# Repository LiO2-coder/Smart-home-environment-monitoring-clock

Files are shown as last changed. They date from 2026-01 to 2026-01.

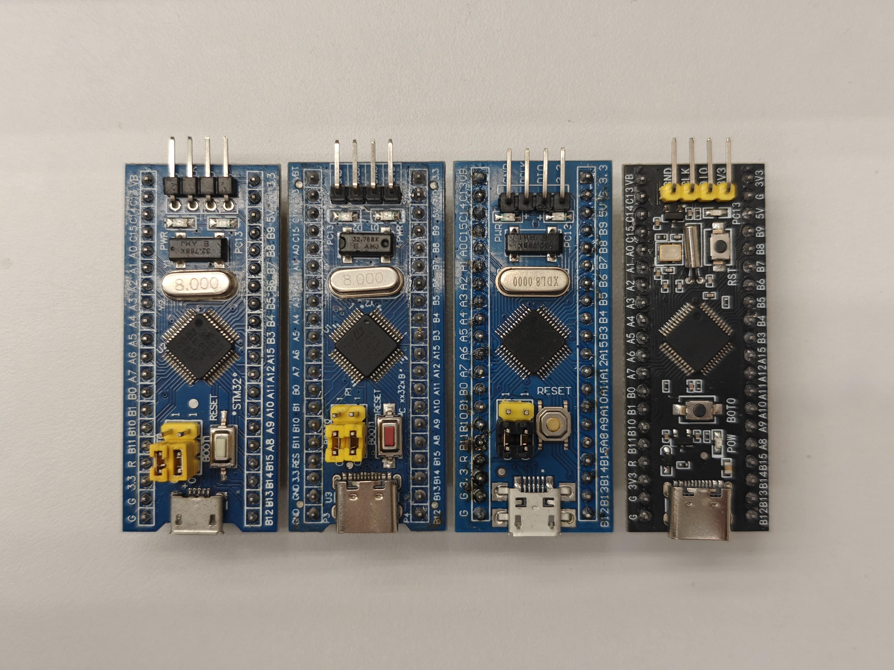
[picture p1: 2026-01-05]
images/调试时-统一使用c8t6.jpg

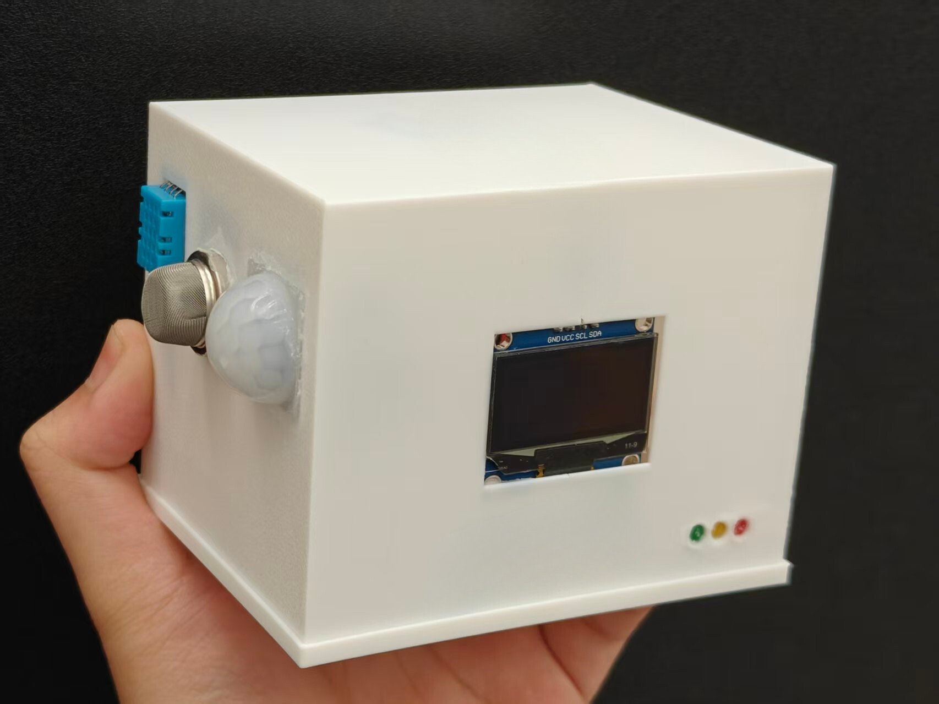
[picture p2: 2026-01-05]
产品实物.jpg

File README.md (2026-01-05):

# 智能居家环境监测时钟系统

## 项目概述
本项目是一个基于STM32与ESP32双核架构的智能家居环境监测时钟系统，实现了环境感知（温湿度、烟雾浓度、光照）、实时时钟显示、语音交互及云端协同等完整功能链。系统创新性地采用人体存在检测雷达触发分级功耗管理，在无人状态下自动进入低功耗模式，整体功耗降低30%以上。

## 核心功能
- **环境监测**：实时采集温湿度、烟雾浓度、光照强度等环境参数
- **智能预警**：多级烟雾浓度预警系统，响应延迟<2秒
- **低功耗管理**：人体存在检测自动触发省电模式
- **双核协同**：STM32负责本地控制，ESP32处理网络通信
- **语音交互**：支持基础语音指令识别与反馈

## 系统架构

### 硬件架构
系统采用模块化设计，STM32作为主控制器，ESP32作为通信协处理器：

### 软件流程
系统启动后并行执行本地控制与网络通信任务：

## 硬件设计

### 硬件连接
项目采用STM32F103ZET6作为主控芯片，外接多种传感器模块：

### 引脚配置
| 序号 | 引脚号 | 连接元件引脚 | 连接元件 |
|---|---|---|---|
| 1 | PA1 | AO | MQ2烟雾传感器 |
| 2 | PA9 | RX | ESP32 AI系统 |
| 3 | PA10 | TX | ESP32 AI系统 |
| 4 | PB0 | OUT | HW416人体检测模块 |
| 5 | PB6 | SCL | OLED显示模块 |
| 6 | PB7 | SDA | OLED显示模块 |

### 实物连接
调试阶段采用杜邦线连接各模块：

## 软件设计

### MQ2烟雾传感器模块
采用ADC采集实现烟雾浓度实时监测：

```c
// ADC初始化配置
hadc1.Instance = ADC1;
hadc1.Init.ScanConvMode = ADC_SCAN_DISABLE;
hadc1.Init.ContinuousConvMode = ENABLE;
```

### 烟雾浓度预警系统
多级阈值触发与分级恢复机制：

```c
typedef enum {
    ALARM_LEVEL_INFO = 0,    // 正常状态
    ALARM_LEVEL_WARNING,     // 警告状态
    ALARM_LEVEL_ERROR,       // 错误状态
} Alarm_Level_t;
```

### DHT11温湿度传感器
单总线通信协议实现数据采集：

```c
void DHT11_IO_OUT() {
    GPIO_InitStruct.Mode = GPIO_MODE_OUTPUT_PP;
    HAL_GPIO_Init(GPIOG, &GPIO_InitStruct);
}
```

### OLED显示模块
开源SSD1306驱动移植，实现信息可视化：

正常显示界面：

省电模式界面：

### RTC实时时钟
后备寄存器机制确保时间持续运行：

```c
void YY_RTC_Init(void) {
    uint32_t initFlag = HAL_RTCEx_BKUPRead(&hrtc, RTC_BKP_DR1);
    if (initFlag == RTC_INIT_FLAG_VALUE) return;
    // 初始化代码
}
```

### STM32-ESP32通信协议
自定义串口通信协议实现双核协同：

```
[AA 55][CMD][LEN][DATA...][CRC16][0D]
```

通信时序流程：

## 调试与开发

### 开发环境
- **主控芯片**：STM32F103ZET6（最终版本）
- **调试芯片**：STM32F103C8T6（开发阶段）
- **开发工具**：Keil MDK-ARM、VSCode
- **调试接口**：SWD、串口调试

### 外壳设计
基于产品需求设计3D打印外壳：

## 项目结构

```
SmartEnvClock/
├── Docs/                    # 项目文档
├── Firmware/               # 嵌入式固件
│   │   ├── Core/           # 核心驱动
│   │   ├── Drivers/        # 硬件驱动
│   │   └── Projects/       # 项目文件
│   └── ESP32/              # ESP32端代码
├── Hardware/               # 硬件设计文件
│   └── 3D_Models/         # 3D外壳模型
└── README.md               # 项目说明
```

## 快速开始

### 硬件准备
1. STM32F103ZET6开发板
2. ESP32-WROOM-32模块
3. OLED显示屏（SSD1306）
4. MQ-2烟雾传感器
5. DHT11温湿度传感器
6. HW416人体检测模块

### 软件编译
1. 克隆仓库
```bash
git clone https://github.com/LiO2-coder/Smart-home-environment-monitoring-clock.git
```

2. 使用Keil打开项目
```bash
打开 /Projects/SAC.uvprojx
```

3. 配置ESP32开发环境
```bash
cd Firmware/ESP32
idf.py build
```

## 通信协议详解

### 协议帧格式
```
帧头(2B) + 命令码(1B) + 数据长度(1B) + 数据(NB) + CRC16(2B) + 帧尾(1B)
```

### 命令码定义
| 命令码 | 功能说明 | 数据长度 |
|---|---|---|
| 0x01 | 请求环境数据 | 0 |
| 0x02 | 请求特定传感器 | 1 |
| 0x10 | 响应就绪 | 0 |
| 0x11 | 发送环境数据 | 20 |

## 性能指标

- **温度测量精度**：±1℃
- **湿度测量精度**：±1%RH
- **烟雾报警响应时间**：<2秒
- **时钟日误差**：<3秒
- **功耗（正常模式）**：120mA
- **功耗（省电模式）**：65mA

## 贡献指南

欢迎提交Issue和Pull Request！主要开发方向包括：

1. **低功耗优化**：进一步降低系统功耗
2. **功能扩展**：增加更多传感器支持
3. **协议优化**：改进通信协议效率
4. **AI集成**：增强本地智能处理能力

## 许可证

本项目采用MIT开源许可证，详见LICENSE文件。

## 联系我们

- 项目主页：https://github.com/LiO2-coder/Smart-home-environment-monitoring-clock
- 问题反馈：https://github.com/LiO2-coder/Smart-home-environment-monitoring-clock/issues
- 邮箱：2099602919@qq.com.com

## 致谢

感谢深圳技术大学嵌入式系统设计课程的支持，特别感谢老师的指导。

---

*最后更新：2026年1月5日*  
*版本号：v1.0.0*

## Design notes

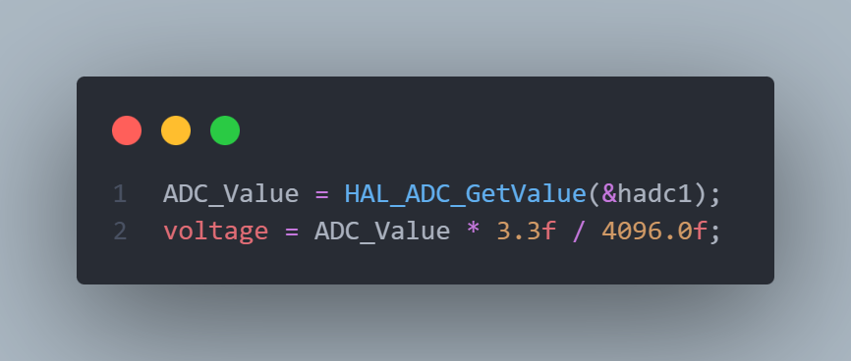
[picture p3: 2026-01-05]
images/MQ2/2.1-ADC-3.png

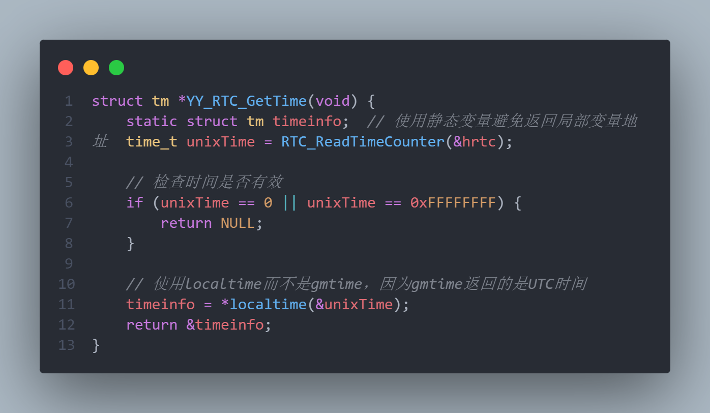
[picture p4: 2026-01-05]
images/rtc/2.5-rtc-4.png

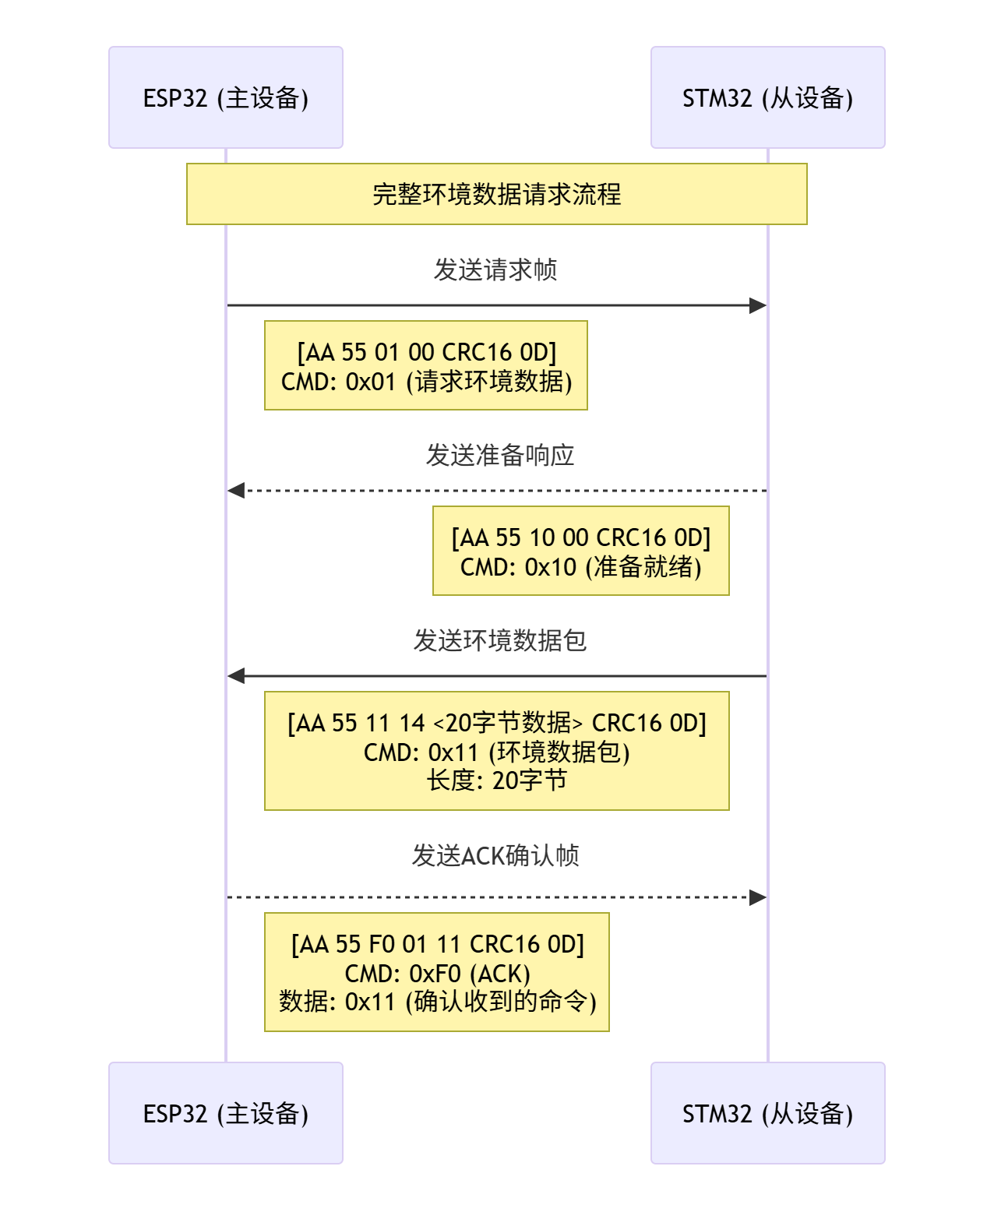
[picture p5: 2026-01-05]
images/双击通信时序流程图.png

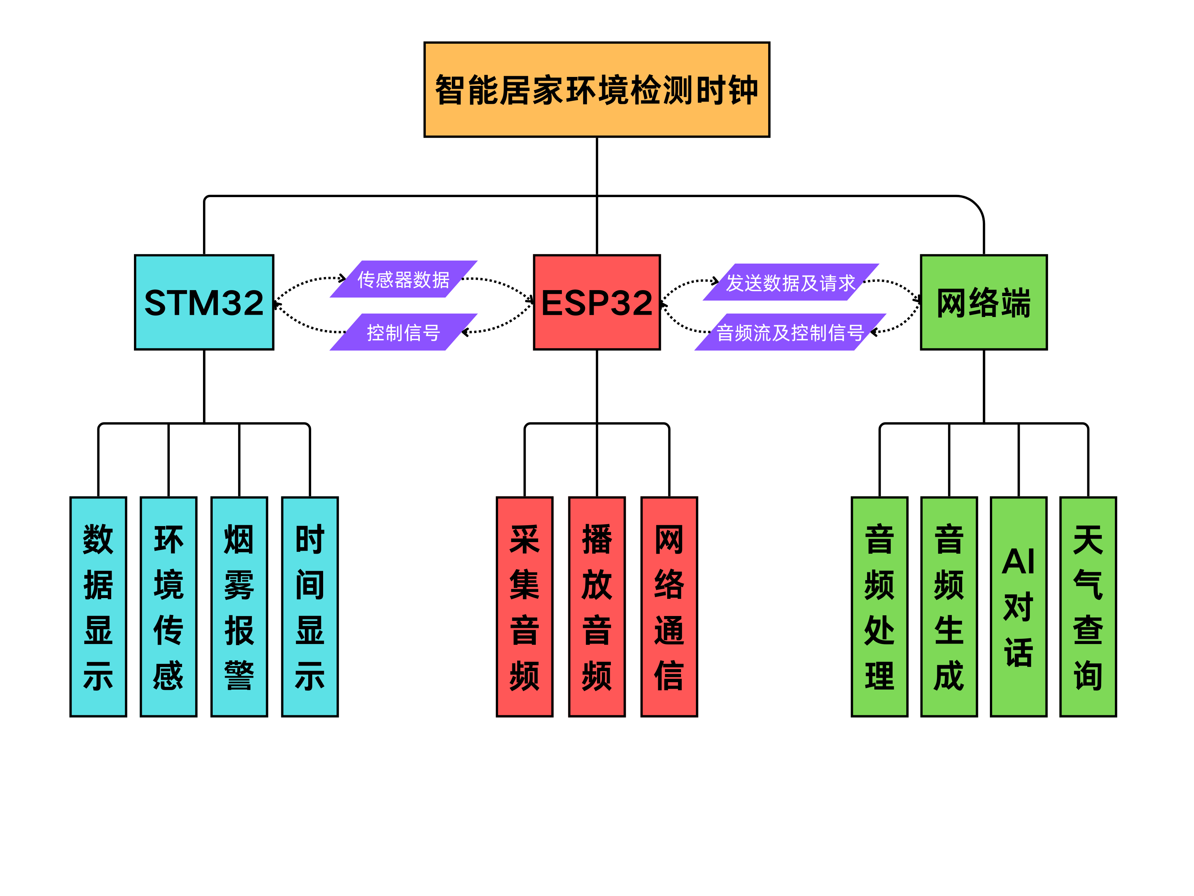
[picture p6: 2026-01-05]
images/框架图.png

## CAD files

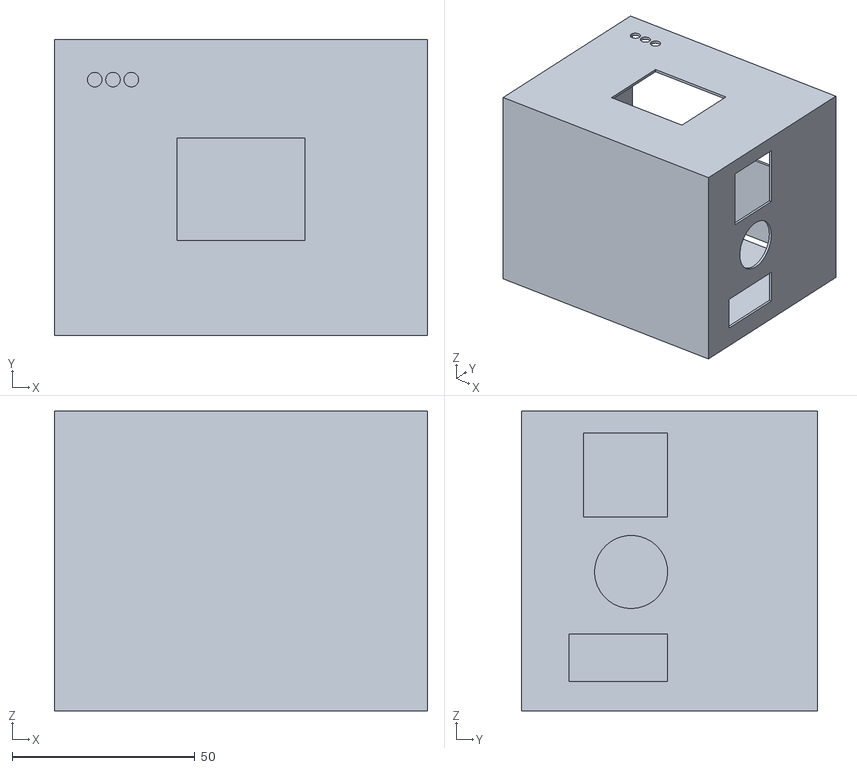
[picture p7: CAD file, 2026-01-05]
Hardware/3D_Models/整体.STL
102.0 x 81.0 x 82.0

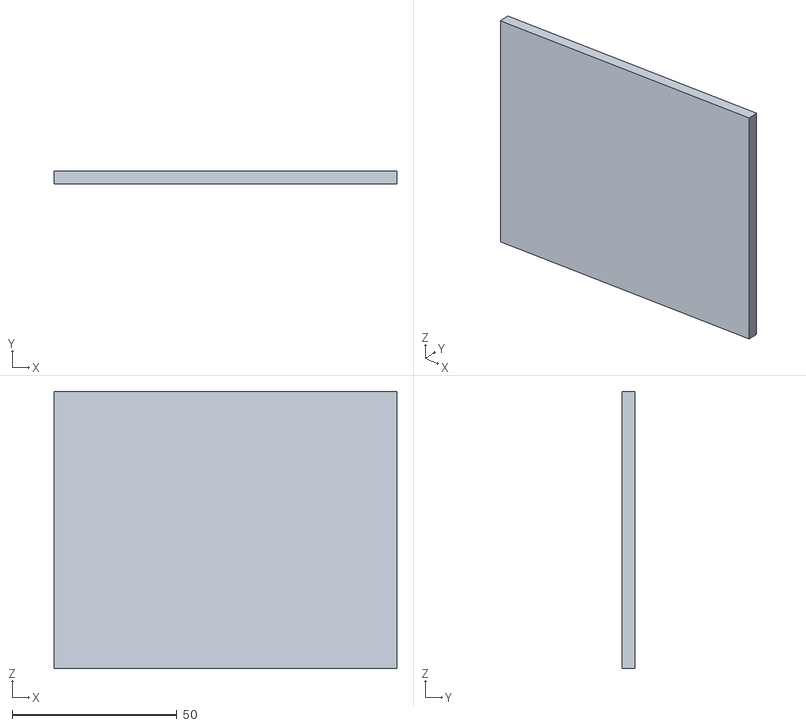
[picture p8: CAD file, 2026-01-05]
Hardware/3D_Models/上盖.STL
104.0 x 4.00 x 84.0

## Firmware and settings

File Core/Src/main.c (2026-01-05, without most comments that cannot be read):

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
/* Includes ------------------------------------------------------------------*/
#include "main.h"
#include "adc.h"
#include "i2c.h"
#include "rtc.h"
#include "gpio.h"

/* USER CODE BEGIN Includes */
#include "oled.h"
#include "DHT11.h"
#include "stdio.h"
#include "string.h"
#include "yy_rtc.h"
#include "Alarm.h"
/* USER CODE END Includes */


void SystemClock_Config(void);
/**
 * @brief  The application entry point.
 * @retval int
 */
int main(void)
{

  /* MCU Configuration--------------------------------------------------------*/

  /* Reset of all peripherals, Initializes the Flash interface and the Systick. */
  HAL_Init();

  /* Configure the system clock */
  SystemClock_Config();

  /* Initialize all configured peripherals */
  MX_GPIO_Init();
  MX_I2C1_Init();
  MX_I2C2_Init();
  MX_ADC1_Init();
  MX_RTC_Init();
  /* USER CODE BEGIN 2 */
  OLED_Init();
  OLED_CLS();


  Alarm_Init();

  // 原有变量定义
  u16 temp = 0;
  u16 humi = 0;
  uint32_t ADC_Value = 0;
  float voltage = 0;
  struct tm *now = NULL;

  char u_temp[20];
  char u_humi[20];
  char u_value[20];
  char ymd[50] = "";
  char hms[50] = "";
  char alarm_status_str[20] = "Status:Normal";

  int fputc(int ch, FILE *f);

  // 显示初始化界面
  OLED_ShowStr(0, 0, "Sensor Monitor", 2);
  OLED_ShowStr(0, 2, "Initializing...", 1);
  HAL_Delay(1000);
  OLED_CLS();
  /* USER CODE END 2 */

  /* Infinite loop */
  /* USER CODE BEGIN WHILE */
  while (1)
  {
    /* USER CODE END WHILE */

    /* USER CODE BEGIN 3 */
    // 如果检测到人体存在
    if (HAL_GPIO_ReadPin(HW416_GPIO_Port, HW416_Pin) == GPIO_PIN_RESET)
    {
      // 正常显示数据


      DHT11_Read_Data(&temp, &humi);


      HAL_GPIO_WritePin(GPIOC, GPIO_PIN_13, GPIO_PIN_RESET);
      HAL_ADC_Start(&hadc1);
      HAL_ADC_PollForConversion(&hadc1, 50);
      ADC_Value = HAL_ADC_GetValue(&hadc1);
      HAL_ADC_Stop(&hadc1);
      HAL_GPIO_WritePin(GPIOC, GPIO_PIN_13, GPIO_PIN_SET);
      voltage = ADC_Value * 3.3f / 4096.0f;

      // 使用新的多级警报系统
      Alarm_Check(voltage);

      // 获取当前警报级别用于显示
      Alarm_Level_t current_level = Alarm_GetCurrentLevel();


      switch (current_level)
      {
      case ALARM_LEVEL_INFO:
        strcpy(alarm_status_str, "Status:Normal");
        break;
      case ALARM_LEVEL_WARNING:
        strcpy(alarm_status_str, "Status:Warning!");
        break;
      case ALARM_LEVEL_ERROR:
        strcpy(alarm_status_str, "Status:ERROR!!");
        break;
      default:
        strcpy(alarm_status_str, "Status:Unknown");
        break;
      }

      // 获取RTC时间
      now = YY_RTC_GetTime();


      sprintf(u_temp, "T:%.1fC", temp / 100.0f);
      sprintf(u_humi, "H:%.1f%%", humi / 100.0f);
      sprintf(u_value, "V:%.2fV", voltage);

      if (now != NULL)
      {
        sprintf(ymd, "%04d-%02d-%02d", now->tm_year + 1900, now->tm_mon + 1, now->tm_mday);
        sprintf(hms, "%02d:%02d:%02d", now->tm_hour, now->tm_min, now->tm_sec);
      }
      else
      {
        strcpy(ymd, "Date: --");
        strcpy(hms, "Time: --");
      }

      // 优化显示布局
      // OLED_CLS();
      OLED_ShowStr(0, 0, (unsigned char *)"Sensor Monitor", 1);
      OLED_ShowStr(100, 0, (unsigned char *)"ON", 1);
      OLED_ShowStr(0, 1, (unsigned char *)u_temp, 1);
      OLED_ShowStr(64, 1, (unsigned char *)u_humi, 1);
      OLED_ShowStr(0, 2, (unsigned char *)u_value, 1);
      OLED_ShowStr(25, 3, (unsigned char *)ymd, 2);
      OLED_ShowStr(32, 5, (unsigned char *)hms, 2);
      OLED_ShowStr(0, 7, (unsigned char *)alarm_status_str, 1);


      /*// char level_indicator[10];
      // sprintf(level_indicator, "Lvl:%d", current_level);
      // OLED_ShowStr(100, 5, (unsigned char *)level_indicator, 1);*/
    }
    else
    {
      // 省电模式显示屏保
      static uint32_t last_blink = 0;
      static uint8_t show_msg = 1;
      uint32_t current_time = HAL_GetTick();

      if (current_time - last_blink > 500)
      {
        show_msg = !show_msg;
        last_blink = current_time;

        OLED_CLS();
        if (show_msg)
        {
          OLED_ShowStr(25, 2.5, (unsigned char *)"Keep Happy", 2);
        }
      }

      // 传感器关闭时重置警报系统
      Alarm_Init();
    }

    HAL_Delay(1000);
  }
  /* USER CODE END 3 */
}

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


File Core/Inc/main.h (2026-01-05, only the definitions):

#define HW416_Pin GPIO_PIN_0
#define HW416_GPIO_Port GPIOB
#define DHT11_Pin GPIO_PIN_4
#define DHT11_GPIO_Port GPIOG
#define Info_Pin GPIO_PIN_1
#define Info_GPIO_Port GPIOD
#define Warning_Pin GPIO_PIN_3
#define Warning_GPIO_Port GPIOD
#define Error_Pin GPIO_PIN_5
#define Error_GPIO_Port GPIOD

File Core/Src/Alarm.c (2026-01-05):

/**
 ******************************************************************************
 * @file    Alarm.c
 * @brief   多级警报系统实现文件 - 采用独立错误恢复机制
 ******************************************************************************
 */

#include "Alarm.h"

// =============================================================================
// 警报系统配置参数
// =============================================================================

// 警报电压阈值定义（单位：伏特）
#define INFO_THRESHOLD 0.0f    // 信息级别电压阈值（正常范围）
#define WARNING_THRESHOLD 0.3f // 警告级别电压阈值（轻微异常）
#define ERROR_THRESHOLD 1.5f   // 错误级别电压阈值（严重异常）

// 警报计数步长定义
#define ALARM_INFO_COUNT 1    // 信息级别计数增量（安全状态）
#define ALARM_WARNING_COUNT 1 // 警告级别计数增量
#define ALARM_ERROR_COUNT 2   // 错误级别计数增量（快速触发）

// 警报触发标志定义
#define ALARM_WARNING_FLAG 3   // 触发警告警报的计数阈值
#define ALARM_ERROR_FLAG 5     // 触发错误警报的计数阈值
#define ALARM_RESET_FLAG 10    // 警告状态复位所需连续安全计数
#define ERROR_RECOVERY_FLAG 15 // 错误状态恢复所需连续安全计数（更严格）

// =============================================================================
// 静态变量定义
// =============================================================================

static uint8_t alarm_count = 0;                              // 警报累计计数器（触发用）
static uint8_t safe_count = 0;                               // 警告状态安全计数器
static uint8_t error_recovery_count = 0;                     // 错误状态恢复计数器（新增）
static bool warning_light_flag = false;                      // 警告灯状态标志
static bool error_light_flag = false;                        // 错误灯状态标志
static Alarm_Level_t current_alarm_level = ALARM_LEVEL_NONE; // 当前警报级别

// =============================================================================
// 硬件控制函数
// =============================================================================

/**
 * @brief  初始化警报系统
 * @note   执行硬件自检，依次点亮各色LED验证硬件连接状态
 * @retval None
 */
void Alarm_Init(void)
{
    // 硬件自检序列：依次点亮各色LED
    HAL_GPIO_WritePin(Info_GPIO_Port, Info_Pin, GPIO_PIN_SET);       // 点亮绿色LED
    HAL_Delay(300);                                                  // 保持100ms
    HAL_GPIO_WritePin(Warning_GPIO_Port, Warning_Pin, GPIO_PIN_SET); // 点亮黄色LED
    HAL_Delay(300);                                                  // 保持100ms
    HAL_GPIO_WritePin(Error_GPIO_Port, Error_Pin, GPIO_PIN_SET);     // 点亮红色LED
    HAL_Delay(300);                                                  // 保持100ms

    // 熄灭所有LED，完成自检
    HAL_GPIO_WritePin(Info_GPIO_Port, Info_Pin, GPIO_PIN_RESET);
    HAL_GPIO_WritePin(Warning_GPIO_Port, Warning_Pin, GPIO_PIN_RESET);
    HAL_GPIO_WritePin(Error_GPIO_Port, Error_Pin, GPIO_PIN_RESET);

    // 初始化状态变量
    current_alarm_level = ALARM_LEVEL_NONE;
    alarm_count = 0;
    safe_count = 0;
    error_recovery_count = 0;
    warning_light_flag = false;
    error_light_flag = false;
}

/**
 * @brief  信息级别警报（绿色LED）
 * @note   表示系统运行正常，仅点亮绿色LED
 * @retval None
 */
void Alarm_Info(void)
{
    HAL_GPIO_WritePin(Info_GPIO_Port, Info_Pin, GPIO_PIN_SET);         // 绿色LED亮
    HAL_GPIO_WritePin(Warning_GPIO_Port, Warning_Pin, GPIO_PIN_RESET); // 黄色LED灭
    HAL_GPIO_WritePin(Error_GPIO_Port, Error_Pin, GPIO_PIN_RESET);     // 红色LED灭
    current_alarm_level = ALARM_LEVEL_INFO;
}

/**
 * @brief  警告级别警报（黄色LED）
 * @note   表示系统存在需要注意的异常，点亮黄色LED
 * @retval None
 */
void Alarm_Warning(void)
{
    HAL_GPIO_WritePin(Info_GPIO_Port, Info_Pin, GPIO_PIN_RESET);     // 绿色LED灭
    HAL_GPIO_WritePin(Warning_GPIO_Port, Warning_Pin, GPIO_PIN_SET); // 黄色LED亮
    HAL_GPIO_WritePin(Error_GPIO_Port, Error_Pin, GPIO_PIN_RESET);   // 红色LED灭
    current_alarm_level = ALARM_LEVEL_WARNING;
}

/**
 * @brief  错误级别警报（红色LED）
 * @note   表示系统存在严重异常需要立即处理，点亮红色LED
 * @retval None
 */
void Alarm_Error(void)
{
    HAL_GPIO_WritePin(Info_GPIO_Port, Info_Pin, GPIO_PIN_RESET);       // 绿色LED灭
    HAL_GPIO_WritePin(Warning_GPIO_Port, Warning_Pin, GPIO_PIN_RESET); // 黄色LED灭
    HAL_GPIO_WritePin(Error_GPIO_Port, Error_Pin, GPIO_PIN_SET);       // 红色LED亮
    current_alarm_level = ALARM_LEVEL_ERROR;
}

// =============================================================================
// 核心逻辑函数
// =============================================================================

/**
 * @brief  安全检查与状态恢复函数（方案二实现）
 * @param  voltage: 当前检测电压值（单位：伏特）
 * @note   采用独立错误恢复计数器机制，实现分级恢复逻辑
 * @retval None
 */
void Safe_Check(float voltage)
{
    // 输入电压有效性检查
    if (voltage < 0)
    {
        voltage = 0.0f; // 负电压强制归零，避免异常处理
    }

    // 仅当电压恢复正常范围（低于警告阈值）时进行恢复判断
    if (voltage < WARNING_THRESHOLD)
    {
        // 分级恢复逻辑：错误级别和警告级别使用不同的恢复机制
        if (current_alarm_level == ALARM_LEVEL_ERROR)
        {
            // 错误级别恢复逻辑：需要更严格的恢复条件
            error_recovery_count += ALARM_INFO_COUNT;

            if (error_recovery_count >= ERROR_RECOVERY_FLAG)
            {
                // 错误状态恢复：重置所有计数器和标志位
                error_recovery_count = 0;
                safe_count = 0;
                alarm_count = 0;
                warning_light_flag = false;
                error_light_flag = false;
                Alarm_Info(); // 恢复到正常状态
            }
        }
        else if (warning_light_flag == true)
        {
            // 警告级别恢复逻辑：使用原有安全计数机制
            safe_count += ALARM_INFO_COUNT;

            if (safe_count >= ALARM_RESET_FLAG)
            {
                // 警告状态恢复：重置相关计数器和标志位
                safe_count = 0;
                alarm_count = 0;
                warning_light_flag = false;
                Alarm_Info(); // 恢复到正常状态
            }
        }
        // 正常状态（ALARM_LEVEL_INFO）无需特殊处理
    }
    else
    {
        // 电压异常：重置所有恢复计数器
        safe_count = 0;
        error_recovery_count = 0;
    }
}

/**
 * @brief  主警报检查函数
 * @param  voltage: 当前检测电压值（单位：伏特）
 * @note   负责警报触发逻辑和状态转移控制
 * @retval None
 */
void Alarm_Check(float voltage)
{
    // 输入电压有效性检查
    if (voltage < 0)
    {
        voltage = 0.0f; // 负电压强制归零
    }

    // 仅当系统未处于激活警报状态时进行触发判断
    if (error_light_flag == false && warning_light_flag == false)
    {
        // 警报级别判断与计数累加
        if (voltage >= ERROR_THRESHOLD)
        {
            // 达到错误级别阈值：快速累计（步长为2）
            alarm_count += ALARM_ERROR_COUNT;
        }
        else if (voltage >= WARNING_THRESHOLD)
        {
            // 达到警告级别阈值：正常累计（步长为1）
            alarm_count += ALARM_WARNING_COUNT;
        }
        // 正常电压范围不进行计数累加

        // 警报状态触发判断
        if (alarm_count >= ALARM_ERROR_FLAG)
        {
            // 触发错误级别警报
            Alarm_Error();
            error_light_flag = true;
            warning_light_flag = true;      // 错误状态包含警告状态
            alarm_count = ALARM_ERROR_FLAG; // 防止计数溢出
        }
        else if (alarm_count >= ALARM_WARNING_FLAG)
        {
            // 触发警告级别警报
            Alarm_Warning();
            warning_light_flag = true;
        }
        // 未达到触发阈值时保持当前状态
    }

    // 执行安全检查与状态恢复（方案二实现）
    Safe_Check(voltage);
}

// =============================================================================
// 状态查询函数（可选扩展）
// =============================================================================
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

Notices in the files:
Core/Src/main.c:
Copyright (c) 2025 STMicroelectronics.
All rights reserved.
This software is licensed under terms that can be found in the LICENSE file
